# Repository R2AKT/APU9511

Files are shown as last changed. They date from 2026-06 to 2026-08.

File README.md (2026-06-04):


License addendum - https://github.com/R2AKT/APU9511/blob/main/Addendum.txt
# APU9511
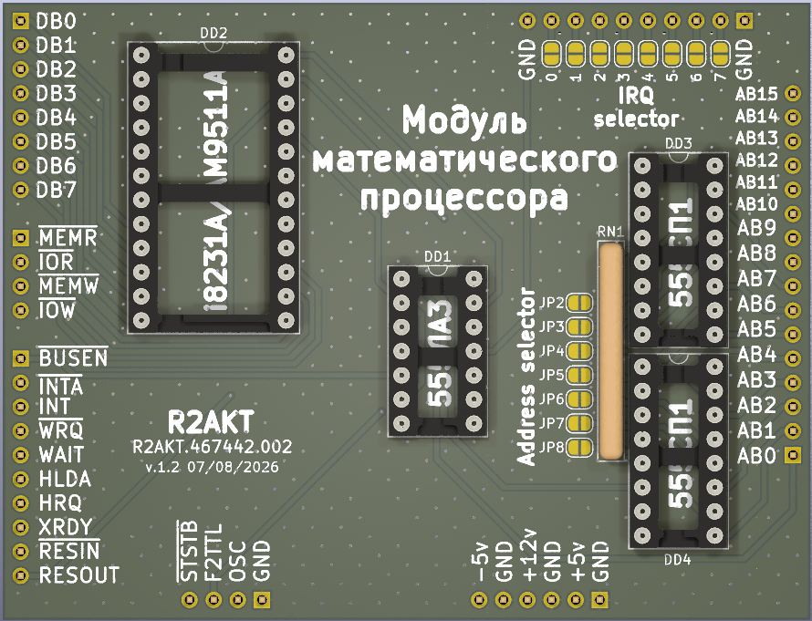
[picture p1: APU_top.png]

APU (Arithmetic Processing Unit) module for CPU_8080 board based on AM9511/8231.
For Mega-80 (Mega-580) DIY 8-bit micro-computer - https://github.com/R2AKT/Mega-80.

*Note: The processor module CPU_8080 must use a 580VK38 (8238) system bus controller, which is not functional when using 580VK28 (8228).

Status: tested.

Модуль математического процессора на базе AM9511/8231.
Для самодельной 8-битной микро-ЭВМ - https://github.com/R2AKT/Mega-80.

*Примечание: в процессорном модуле CPU_8080 должен применяться контроллер системной шины 580ВК38 (8238), при использовании 580ВК28 (8228) не работоспособно.

Статус: проверено.

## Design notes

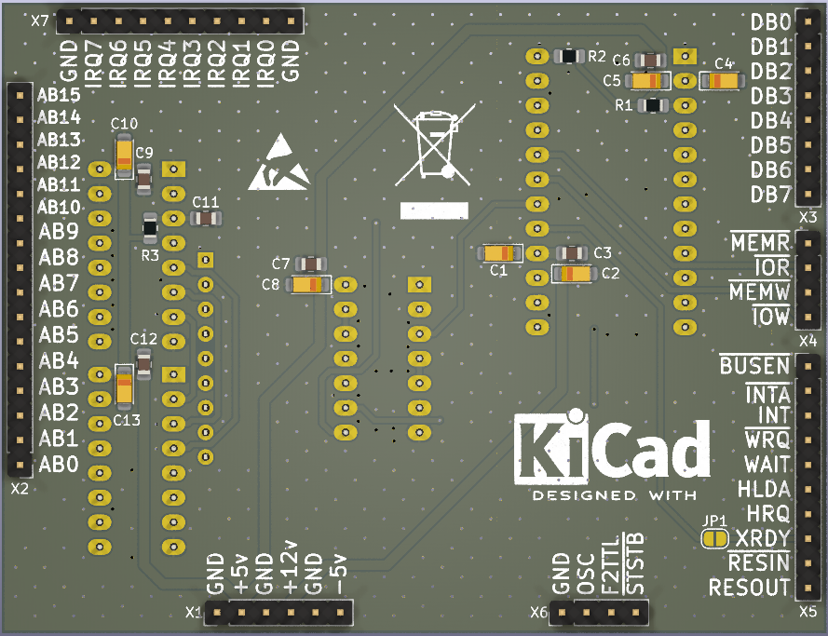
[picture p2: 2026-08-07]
APU_btn.png

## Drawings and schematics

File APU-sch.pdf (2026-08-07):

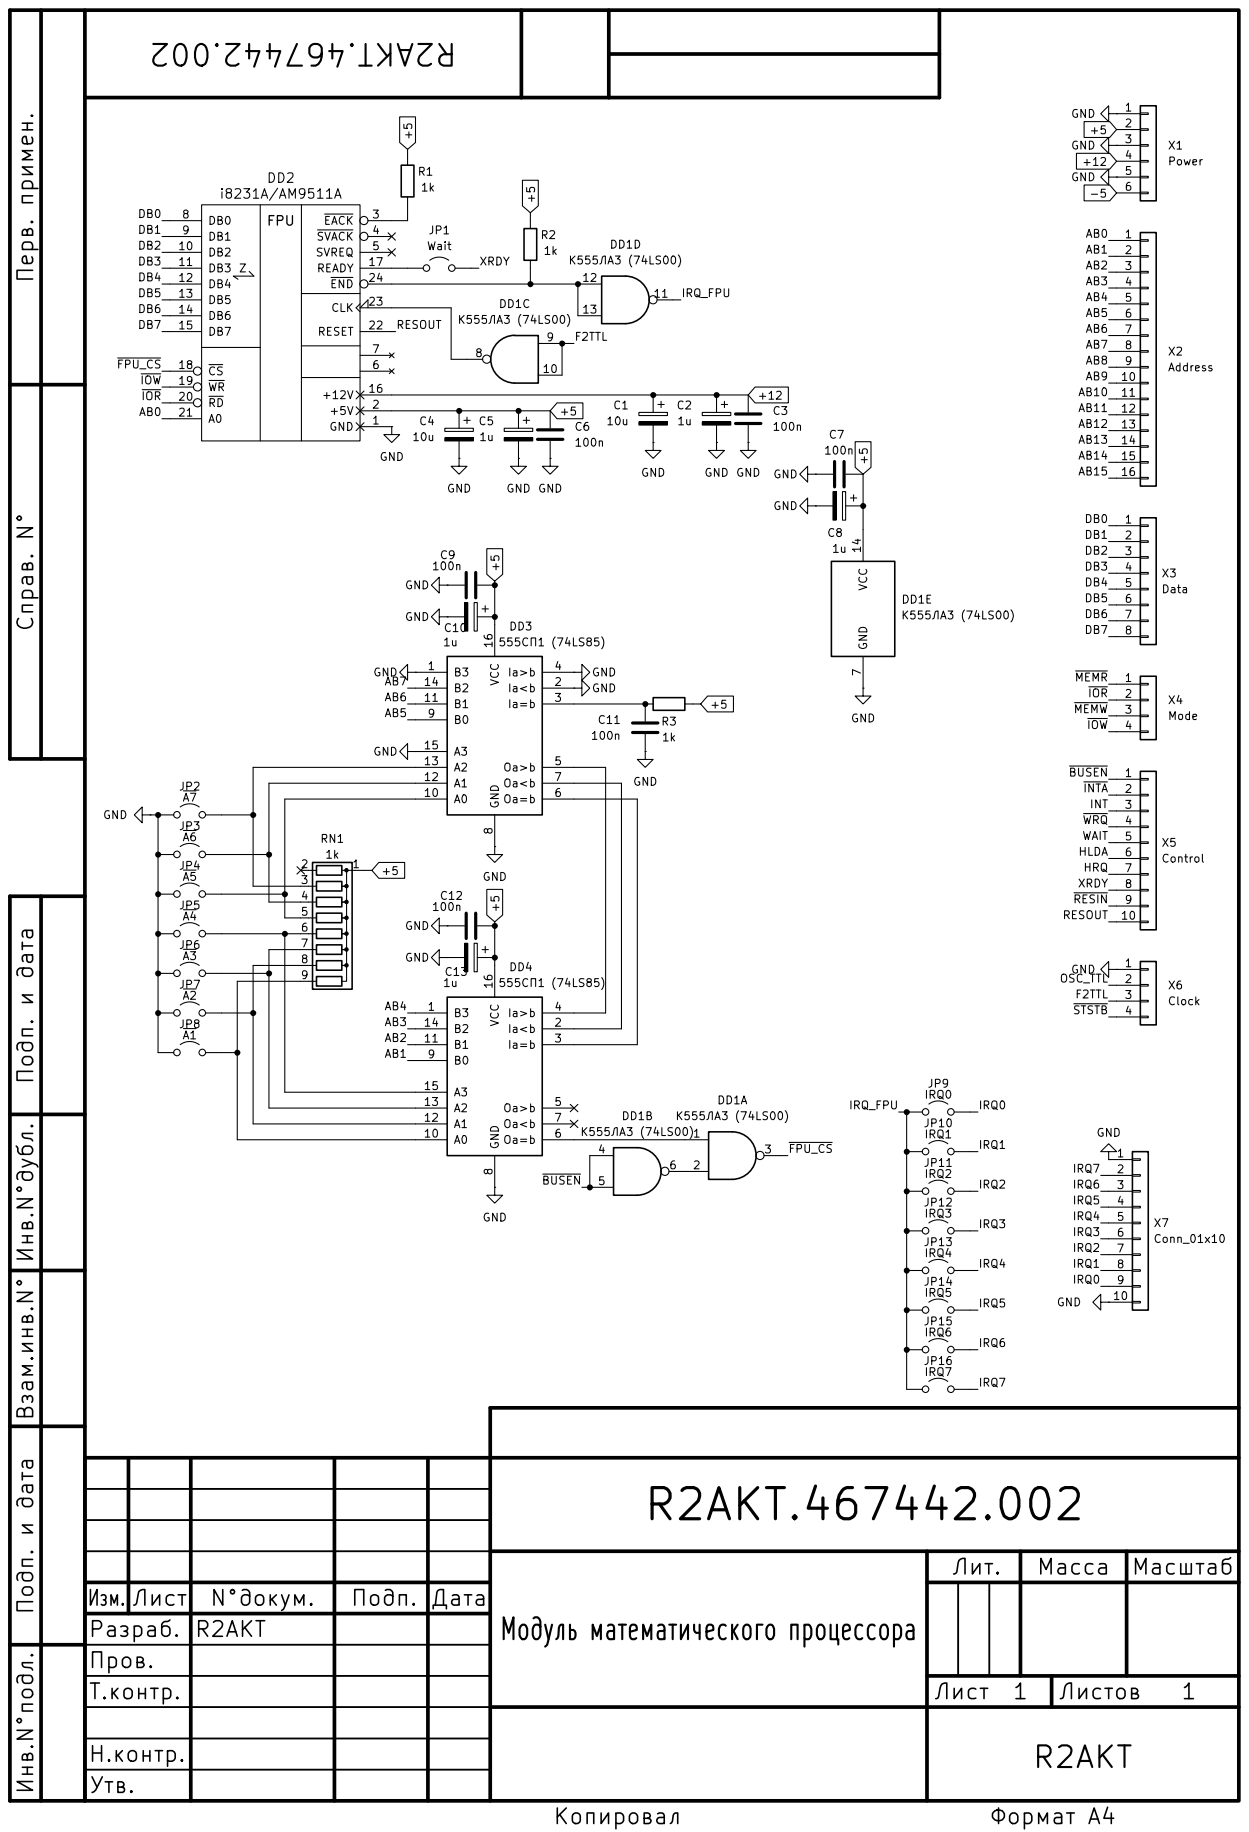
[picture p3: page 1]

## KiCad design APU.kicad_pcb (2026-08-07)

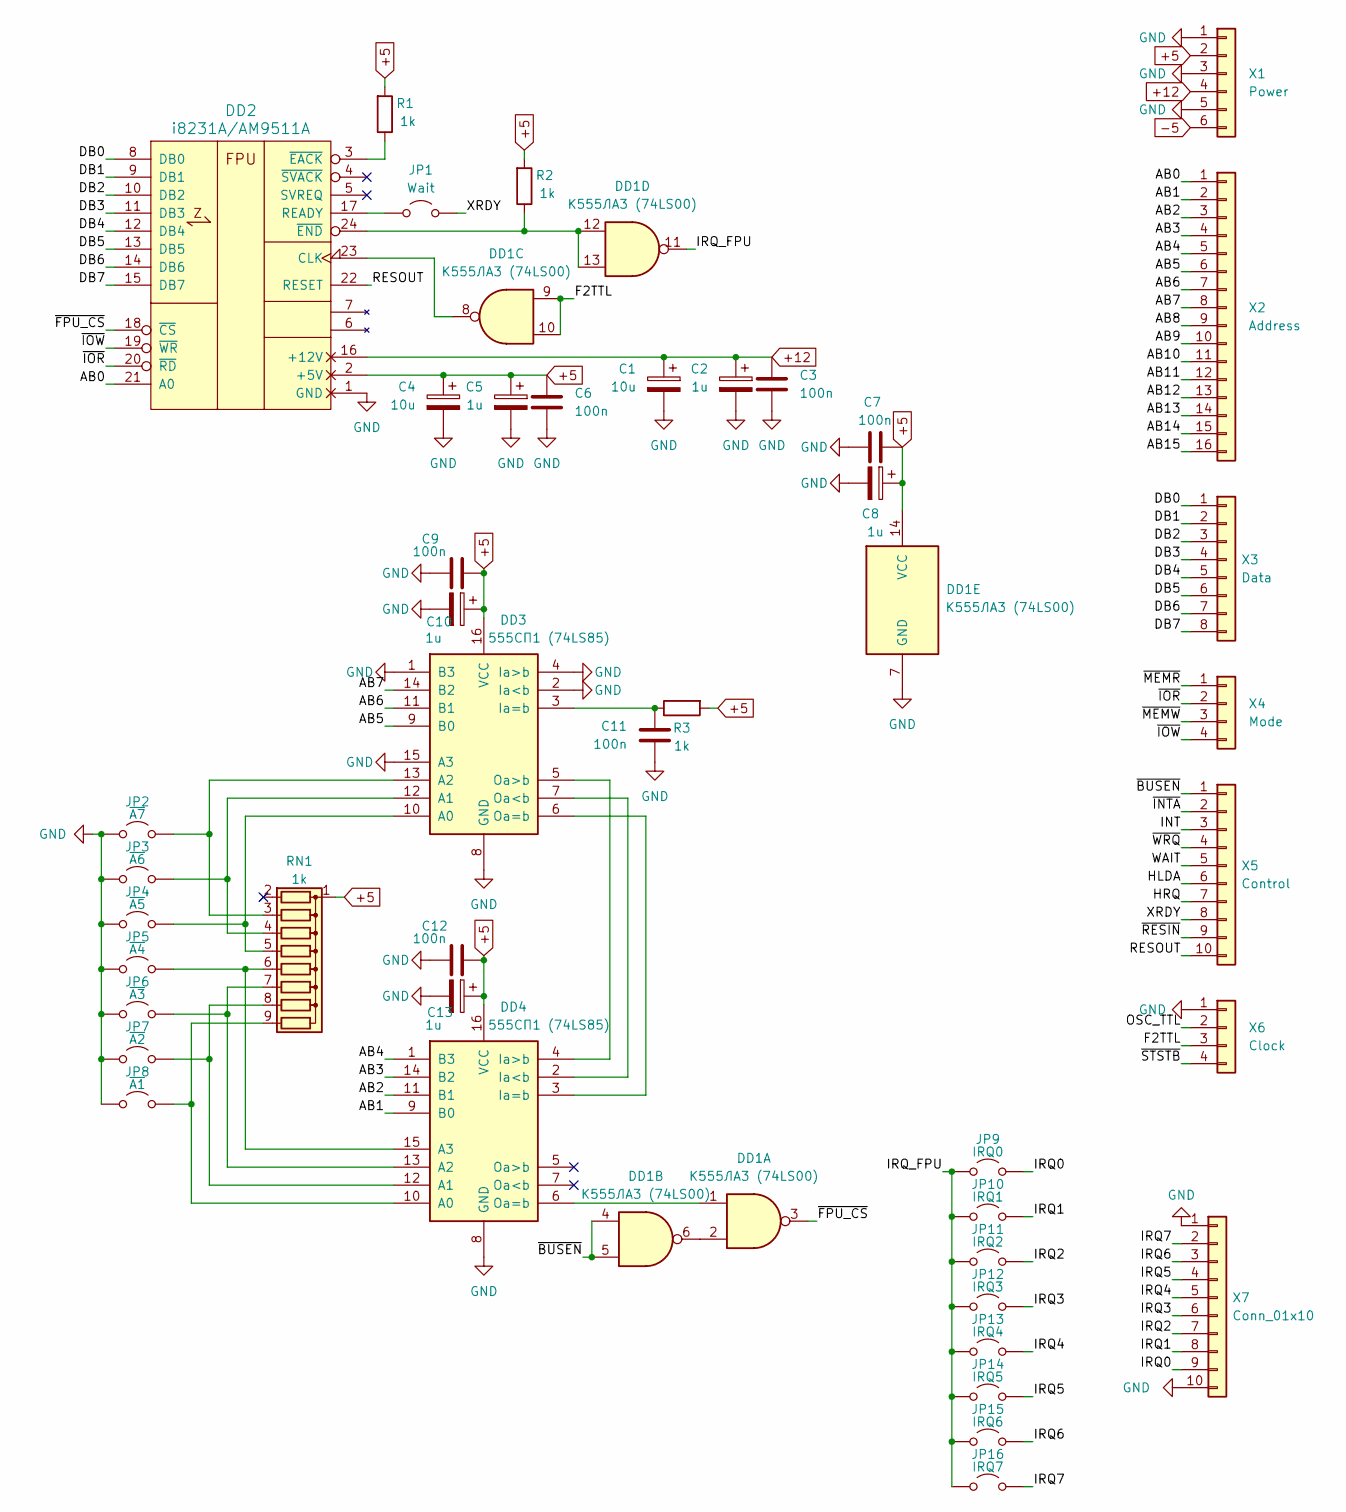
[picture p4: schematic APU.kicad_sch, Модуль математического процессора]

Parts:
C1, C4: 10u; CP_EIA-3216-18_Kemet-A_Pad1.58x1.35mm_HandSolder
C2, C5, C8, C10, C13: 1u; CP_EIA-3216-18_Kemet-A_Pad1.58x1.35mm_HandSolder
C3, C6, C7, C9, C11, C12: 100n; C_0805_2012Metric_Pad1.18x1.45mm_HandSolder
DD1: К555ЛА3 (74LS00); DIP-14_W7.62mm_Socket_LongPads
DD2: i8231A/AM9511A; DIP-24_W15.24mm_Socket_LongPads
DD3, DD4: 555СП1 (74LS85); DIP-16_W7.62mm_Socket_LongPads
JP1: Wait; SolderJumper-2_P1.3mm_Open_RoundedPad1.0x1.5mm
JP2: ~{A7}; SolderJumper-2_P1.3mm_Open_RoundedPad1.0x1.5mm
JP3: ~{A6}; SolderJumper-2_P1.3mm_Open_RoundedPad1.0x1.5mm
JP4: ~{A5}; SolderJumper-2_P1.3mm_Open_RoundedPad1.0x1.5mm
JP5: ~{A4}; SolderJumper-2_P1.3mm_Open_RoundedPad1.0x1.5mm
JP6: ~{A3}; SolderJumper-2_P1.3mm_Open_RoundedPad1.0x1.5mm
JP7: ~{A2}; SolderJumper-2_P1.3mm_Open_RoundedPad1.0x1.5mm
JP8: ~{A1}; SolderJumper-2_P1.3mm_Open_RoundedPad1.0x1.5mm
JP9: IRQ0; SolderJumper-2_P1.3mm_Open_RoundedPad1.0x1.5mm
JP10: IRQ1; SolderJumper-2_P1.3mm_Open_RoundedPad1.0x1.5mm
JP11: IRQ2; SolderJumper-2_P1.3mm_Open_RoundedPad1.0x1.5mm
JP12: IRQ3; SolderJumper-2_P1.3mm_Open_RoundedPad1.0x1.5mm
JP13: IRQ4; SolderJumper-2_P1.3mm_Open_RoundedPad1.0x1.5mm
JP14: IRQ5; SolderJumper-2_P1.3mm_Open_RoundedPad1.0x1.5mm
JP15: IRQ6; SolderJumper-2_P1.3mm_Open_RoundedPad1.0x1.5mm
JP16: IRQ7; SolderJumper-2_P1.3mm_Open_RoundedPad1.0x1.5mm
R1, R2, R3: 1k; R_0805_2012Metric_Pad1.20x1.40mm_HandSolder
RN1: 1k; R_Array_SIP9
X1: Power; PinHeader_1x06_P2.54mm_Vertical
X2: Address; PinHeader_1x16_P2.54mm_Vertical
X3: Data; PinHeader_1x08_P2.54mm_Vertical
X4: Mode; PinHeader_1x04_P2.54mm_Vertical
X5: Control; PinHeader_1x10_P2.54mm_Vertical
X6: Clock; PinHeader_1x04_P2.54mm_Vertical
X7: Conn_01x10; PinHeader_1x10_P2.54mm_Vertical

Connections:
+5: C4.1, C5.1, C6.1, C7.1, C8.1, C9.1, C10.1, C12.1, C13.1, DD1.14 (VCC), DD2.2 (+5V), DD3.16 (VCC), DD4.16 (VCC), R1.2, R2.2, R3.2, RN1.1 (common), X1.2
+12: C1.1, C2.1, C3.1, DD2.16 (+12V), X1.4
-5: X1.6
/AB0: DD2.21 (A0), X2.1
/AB1: DD4.9 (B0), X2.2
/AB2: DD4.11 (B1), X2.3
/AB3: DD4.14 (B2), X2.4
/AB4: DD4.1 (B3), X2.5
/AB5: DD3.9 (B0), X2.6
/AB6: DD3.11 (B1), X2.7
/AB7: DD3.14 (B2), X2.8
/AB8: X2.9
/AB9: X2.10
/AB10: X2.11
/AB11: X2.12
/AB12: X2.13
/AB13: X2.14
/AB14: X2.15
/AB15: X2.16
/DB0: DD2.8 (DB0), X3.1
/DB1: DD2.9 (DB1), X3.2
/DB2: DD2.10 (DB2), X3.3
/DB3: DD2.11 (DB3), X3.4
/DB4: DD2.12 (DB4), X3.5
/DB5: DD2.13 (DB5), X3.6
/DB6: DD2.14 (DB6), X3.7
/DB7: DD2.15 (DB7), X3.8
/F2TTL: DD1.9, DD1.10, X6.3
/HLDA: X5.6
/HRQ: X5.7
/INT: X5.3
/IRQ0: JP9.2 (B), X7.9
/IRQ1: JP10.2 (B), X7.8
/IRQ2: JP11.2 (B), X7.7
/IRQ3: JP12.2 (B), X7.6
/IRQ4: JP13.2 (B), X7.5
/IRQ5: JP14.2 (B), X7.4
/IRQ6: JP15.2 (B), X7.3
/IRQ7: JP16.2 (B), X7.2
/IRQ_FPU: DD1.11, JP9.1 (A), JP10.1 (A), JP11.1 (A), JP12.1 (A), JP13.1 (A), JP14.1 (A), JP15.1 (A), JP16.1 (A)
/OSC_TTL: X6.2
/RESOUT: DD2.22 (RESET), X5.10
/WAIT: X5.5
/XRDY: JP1.2 (B), X5.8
/~BUSEN: DD1.4, DD1.5, X5.1
/~FPU_CS: DD1.3, DD2.18 (~CS)
/~INTA: X5.2
/~IOR: DD2.20 (~RD), X4.2
/~IOW: DD2.19 (~WR), X4.4
/~MEMR: X4.1
/~MEMW: X4.3
/~RESIN: X5.9
/~STSTB: X6.4
/~WRQ: X5.4
GND: C1.2, C2.2, C3.2, C4.2, C5.2, C6.2, C7.2, C8.2, C9.2, C10.2, C11.2, C12.2, C13.2, DD1.7 (GND), DD2.1 (GND), DD3.1 (B3), DD3.2 (Ia<b), DD3.4 (Ia>b), DD3.8 (GND), DD3.15 (A3), DD4.8 (GND), JP2.1 (A), JP3.1 (A), JP4.1 (A), JP5.1 (A), JP6.1 (A), JP7.1 (A), JP8.1 (A), X1.1, X1.3, X1.5, X6.1, X7.1, X7.10
unnamed: DD1.2, DD1.6
unnamed: DD1.8, DD2.23 (CLK)
unnamed: DD2.17 (READY), JP1.1 (A)
unnamed: DD2.3 (~EACK), R1.1
unnamed: DD1.12, DD1.13, DD2.24 (~END), R2.1
unnamed: DD3.10 (A0), JP4.2 (B), RN1.5 (R4)
unnamed: DD3.12 (A1), JP3.2 (B), RN1.4 (R3)
unnamed: DD3.13 (A2), JP2.2 (B), RN1.3 (R2)
unnamed: C11.1, DD3.3 (Ia=b), R3.1
unnamed: DD3.7 (Oa<b), DD4.2 (Ia<b)
unnamed: DD3.6 (Oa=b), DD4.3 (Ia=b)
unnamed: DD3.5 (Oa>b), DD4.4 (Ia>b)
unnamed: DD4.10 (A0), JP8.2 (B), RN1.9 (R8)
unnamed: DD4.12 (A1), JP7.2 (B), RN1.8 (R7)
unnamed: DD4.13 (A2), JP6.2 (B), RN1.7 (R6)
unnamed: DD4.15 (A3), JP5.2 (B), RN1.6 (R5)
unnamed: DD1.1, DD4.6 (Oa=b)

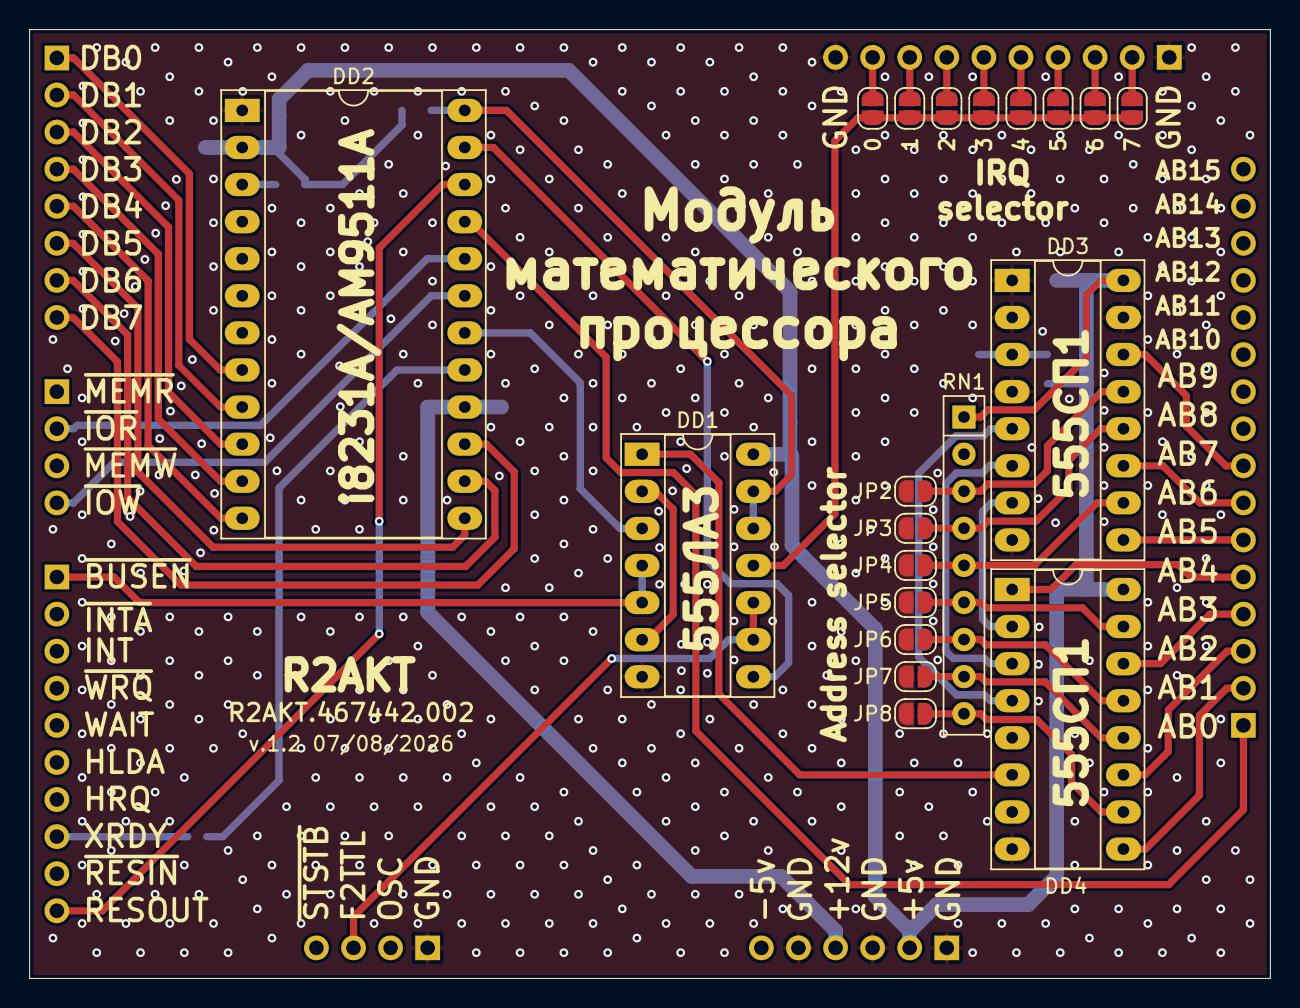
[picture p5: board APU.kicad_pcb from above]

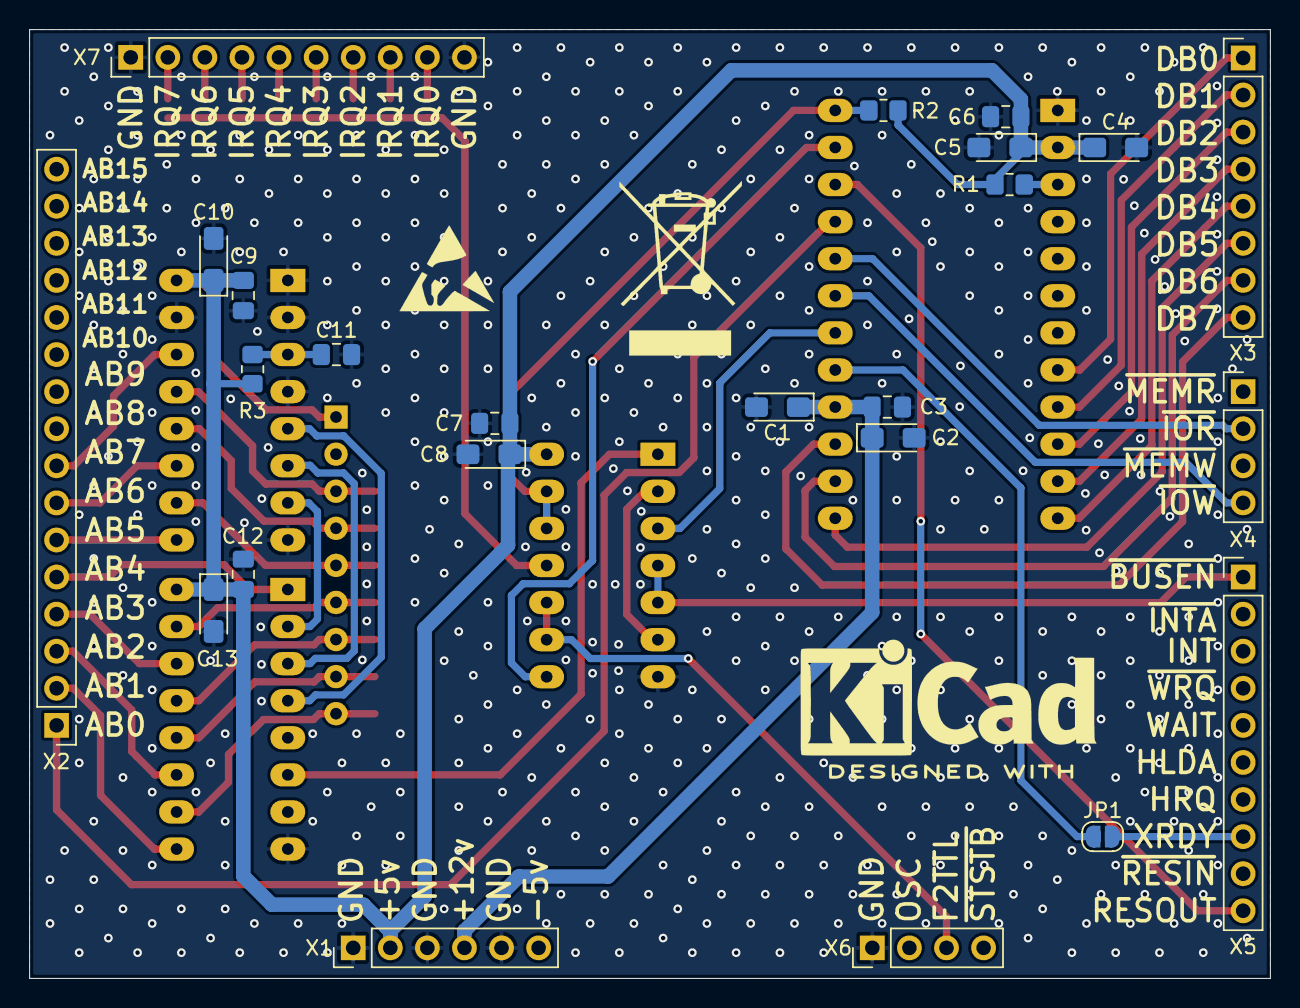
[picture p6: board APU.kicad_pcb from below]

Board: 2 copper layers, 85.0 x 65.0 mm, 44 parts (24 on the bottom side), 52 nets.

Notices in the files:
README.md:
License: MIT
